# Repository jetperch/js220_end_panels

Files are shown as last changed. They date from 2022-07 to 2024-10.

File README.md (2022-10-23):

# Joulescope Front Panels

Welcome to Joulescope™ JS220 front panel hardware design project.  This project 
contains the open source hardware designs for a variety of JS220 front
panels.  These front panels customize Joulescope so that it can more easily 
connect to your power supply and target device.
For more information on Joulescope, see 
[www.joulescope.com](https://www.joulescope.com).

The [Baseline PDF](eagle/fp_baseline/fp_baseline.pdf) show the board outline
and critical dimensions.

The 2x3 connector to the main board is
[Samtec TSM-103-01-S-DV-A](https://www.samtec.com/products/tsm-103-01-s-dv-a)
([Mouser](https://www.mouser.com/ProductDetail/Samtec/TSM-103-01-S-DV-A?qs=0lQeLiL1qyYnWtGorwZW9A%3D%3D),
[Digi-Key](https://www.digikey.com/en/products/detail/TSM-103-01-S-DV-A/TSM-103-01-S-DV-A-ND/2685555))

The boards have been fabricated using PCBWay. 
Here are the order notes ([example](pcbway_order.png)):

* Size: 95 x 24.7 mm
* FR-4, TG 150-160, 1.6 thick, 6/6, 0.3 mm min hole size
* Solder Mask: Black, White silkscreen
* Surface Finish: HASL lead free, do NOT check accept ENIG substitution
* Finished Copper 1 oz

Special requests text:
The front-side surface is cosmetic.  
Reject units with scratches and blemishes.
Place all markings on back, including pcb product number.
Add flammability rating marking on back, such as 94V-0.

## License

All Joulescope front-panel designs are released under the 
permissive Apache 2.0 license.

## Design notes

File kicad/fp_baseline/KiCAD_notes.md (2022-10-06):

# KiCAD Notes

The symbol and footprint components / libraries have been generated for KiCAD V6 and are not anticipated to be backwards compatible.

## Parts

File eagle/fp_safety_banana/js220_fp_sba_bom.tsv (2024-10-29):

Quantity | Part | Designators
1 | CT3149-0 | J1
2 | CT3149-2 | J2,J3
1 | CT3149-4 | J4
1 | TSM-103-01-S-DV-A | J5
1 | JS220_fp_sba_pcb_revB | PCB1

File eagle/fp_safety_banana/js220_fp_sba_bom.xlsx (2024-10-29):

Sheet: All
BOM - All
2024 October 29
# | Qty | Ref Des | Name
1 | 1 | J1 | CT3149-0
2 | 2 | J2, J3 | CT3149-2
3 | 1 | J4 | CT3149-4
4 | 1 | J5 | TSM-103-01-S-DV-A
5 | 1 | PCB1 | JS220_fp_sba_pcb_revB
 | 6

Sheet: Top
BOM - Top
2024 October 29
# | Qty | Ref Des | Name
1 | 1 | J1 | CT3149-0
2 | 2 | J2, J3 | CT3149-2
3 | 1 | J4 | CT3149-4
4 | 1 | J5 | TSM-103-01-S-DV-A
5 | 1 | PCB1 | JS220_fp_sba_pcb_revB
 | 6

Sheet: Bottom
BOM - Bottom
2024 October 29
# | Qty | Ref Des | Name
 | 0

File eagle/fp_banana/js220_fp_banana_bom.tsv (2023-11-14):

Quantity | Part | Designators
1 | CT3151V1-0 | J1
2 | CT3151V1-2 | J2,J3
1 | CT3151V1-4 | J4
1 | TSM-103-01-S-DV-A | J5
1 | JS220_fp_banana_pcb_revA | PCB1

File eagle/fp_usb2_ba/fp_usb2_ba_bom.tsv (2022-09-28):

Quantity | Part | Designators
1 | M701-330442 | J1
1 | TSM-103-01-S-DV-A | J5
1 | UJ2-AV-1-TH | J2
1 | JS220_fp_usb2_ba_pcb_revB | PCB1

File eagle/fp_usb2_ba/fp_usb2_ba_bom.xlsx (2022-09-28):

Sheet: All
BOM - All
2022 September 28
# | Qty | Ref Des | Name
1 | 1 | J1 | M701-330442
2 | 1 | J5 | TSM-103-01-S-DV-A
3 | 1 | J2 | UJ2-AV-1-TH
4 | 1 | PCB1 | JS220_fp_usb2_ba_pcb_revB
 | 4

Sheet: Top
BOM - Top
2022 September 28
# | Qty | Ref Des | Name
1 | 1 | J1 | M701-330442
2 | 1 | J5 | TSM-103-01-S-DV-A
3 | 1 | J2 | UJ2-AV-1-TH
4 | 1 | PCB1 | JS220_fp_usb2_ba_pcb_revB
 | 4

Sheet: Bottom
BOM - Bottom
2022 September 28
# | Qty | Ref Des | Name
 | 0

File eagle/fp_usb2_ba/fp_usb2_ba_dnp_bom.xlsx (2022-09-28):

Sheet: All
BOM - All
2022 September 28
# | Qty | Ref Des | Name
1 | 3 | H1, H2, J3 | DNI
 | 3

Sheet: Top
BOM - Top
2022 September 28
# | Qty | Ref Des | Name
1 | 3 | H1, H2, J3 | DNI
 | 3

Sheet: Bottom
BOM - Bottom
2022 September 28
# | Qty | Ref Des | Name
 | 0

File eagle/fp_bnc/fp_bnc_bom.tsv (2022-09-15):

Quantity | Part | Designators
2 | 031-5329-52RFX | J1,J2
1 | TSM-103-01-S-DV-A | J5
1 | JS220_fp_bnc_pcb_revA | PCB1

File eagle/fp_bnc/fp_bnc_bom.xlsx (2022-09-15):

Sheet: All
BOM - All
2022 September 15
# | Qty | Ref Des | Name
1 | 2 | J1, J2 | 031-5329-52RFX
2 | 1 | J5 | TSM-103-01-S-DV-A
3 | 1 | PCB1 | JS220_fp_bnc_pcb_revA
 | 4

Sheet: Top
BOM - Top
2022 September 15
# | Qty | Ref Des | Name
1 | 2 | J1, J2 | 031-5329-52RFX
2 | 1 | J5 | TSM-103-01-S-DV-A
3 | 1 | PCB1 | JS220_fp_bnc_pcb_revA
 | 4

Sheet: Bottom
BOM - Bottom
2022 September 15
# | Qty | Ref Des | Name
 | 0

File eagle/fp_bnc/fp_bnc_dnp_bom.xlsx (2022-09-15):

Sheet: All
BOM - All
2022 September 15
# | Qty | Ref Des | Name
1 | 8 | C1, C2, H1, H2, J3, J4, R1, R2 | DNI
 | 8

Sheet: Top
BOM - Top
2022 September 15
# | Qty | Ref Des | Name
1 | 8 | C1, C2, H1, H2, J3, J4, R1, R2 | DNI
 | 8

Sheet: Bottom
BOM - Bottom
2022 September 15
# | Qty | Ref Des | Name
 | 0

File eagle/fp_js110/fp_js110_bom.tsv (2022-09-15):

Quantity | Part | Designators
2 | CT3149-0 | J1,J3
2 | CT3149-2 | J2,J4
1 | TSM-103-01-S-DV-A | J5
1 | JS220_fp_js110_pcb_revA | PCB1

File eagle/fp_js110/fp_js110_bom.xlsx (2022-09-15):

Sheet: All
BOM - All
2022 September 15
# | Qty | Ref Des | Name
1 | 2 | J1, J3 | CT3149-0
2 | 2 | J2, J4 | CT3149-2
3 | 1 | J5 | TSM-103-01-S-DV-A
4 | 1 | PCB1 | JS220_fp_js110_pcb_revA
 | 6

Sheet: Top
BOM - Top
2022 September 15
# | Qty | Ref Des | Name
1 | 2 | J1, J3 | CT3149-0
2 | 2 | J2, J4 | CT3149-2
3 | 1 | J5 | TSM-103-01-S-DV-A
4 | 1 | PCB1 | JS220_fp_js110_pcb_revA
 | 6

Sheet: Bottom
BOM - Bottom
2022 September 15
# | Qty | Ref Des | Name
 | 0

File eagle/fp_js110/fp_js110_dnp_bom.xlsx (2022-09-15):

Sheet: All
BOM - All
2022 September 15
# | Qty | Ref Des | Name
1 | 4 | H1, H2, J6, R1 | DNI
 | 4

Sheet: Top
BOM - Top
2022 September 15
# | Qty | Ref Des | Name
1 | 4 | H1, H2, J6, R1 | DNI
 | 4

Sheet: Bottom
BOM - Bottom
2022 September 15
# | Qty | Ref Des | Name
 | 0

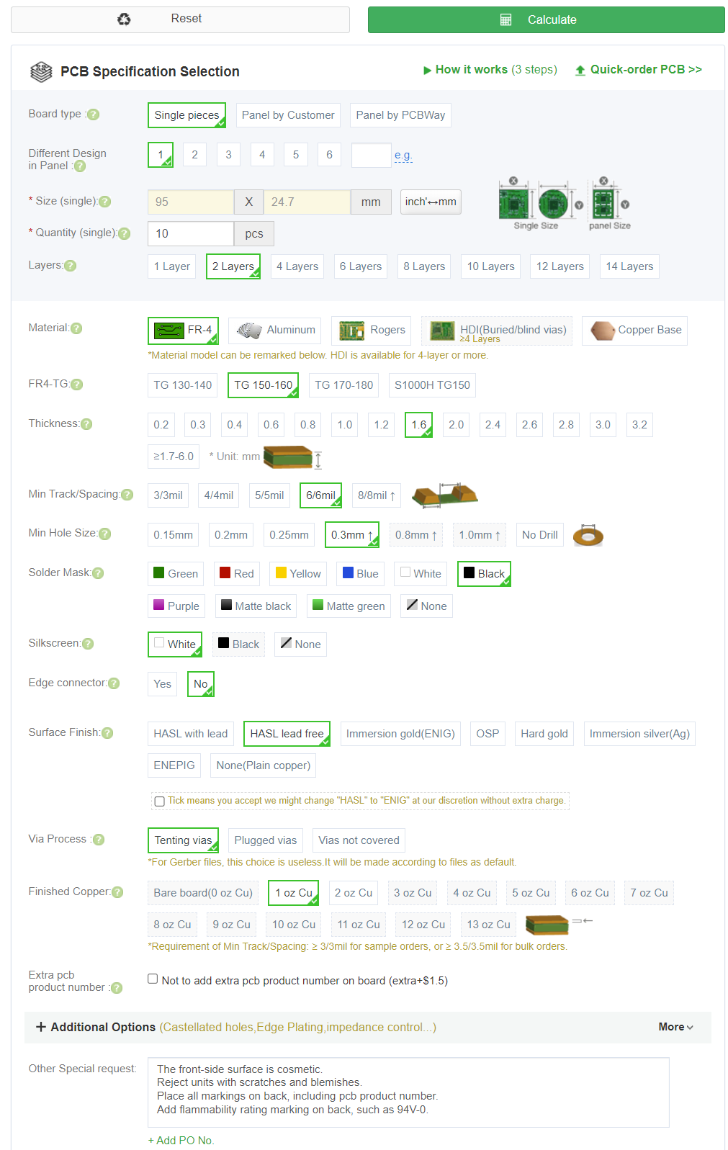
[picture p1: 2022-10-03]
pcbway_order.png

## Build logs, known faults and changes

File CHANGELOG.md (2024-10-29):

# CHANGELOG

This file contains the list of changes made to joulescope_front_panels.

## 1.1.0

2024 Oct 29

* Added JS220 Safety Banana Jack front panel.

## 1.0.3

2022 Oct 23

* Added connector part number to README.

## 1.0.2

2022 Oct 3

* Improved fp_baseline dimensioning.
* Added fp_baseline.pdf.
* First public release.
* Added PCBWay order example.

## 1.0.1

2022 Sep 28

* Fixed fb_usb2_ba connector A USB connector holes.

## 1.0.0

2022 Sep 15

* Updated back panel for production build.
  * Increased USB hole size by 0.2 mm in left, right, and up directions
  * Bumped rev from C to D.
* Added additional boards:
  * fb_usb2_ba: USB 2.0 B/A connector
  * fp_bnc: BNC & 0.1" headers
  * fp_js110: Safety banana jacks configured like the JS110.
  * fp_baseline: Starting point for creating new boards in Eagle.

## 0.3.0

2022 Jun 16

* Updated binding post front panel for beta build.
  * Decreased TSM-103-01-S-DV-A alignment holes from 0.068" to 0.065".
    Spec'ed sized is 0.063"
* Updated back panel for beta build.
  * Increased USB hole size by 0.15 mm in all directions.
  * Fixed BNC hole.
    * Decreased diameter from 10.45 to 10.05 mm.
    * Moved up from 11.555 mm to 12.355 to account for PCB thickness.
    * Tighted up polarizing holes vertically & horizontally.

## 0.2.0

2022 Feb 17

* Updated for JS220 p3.

## 0.1.0

2021 Jul 23

* Initial release with binding post front panel and back panel.

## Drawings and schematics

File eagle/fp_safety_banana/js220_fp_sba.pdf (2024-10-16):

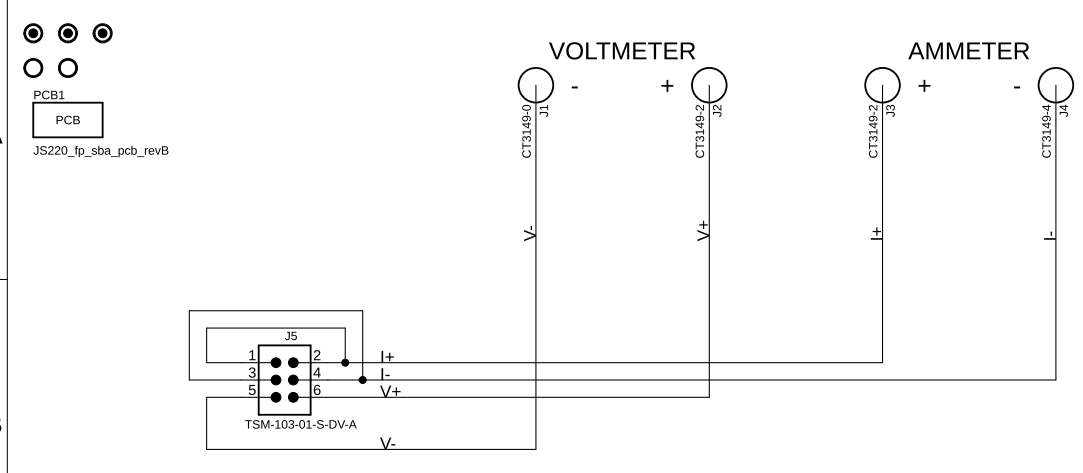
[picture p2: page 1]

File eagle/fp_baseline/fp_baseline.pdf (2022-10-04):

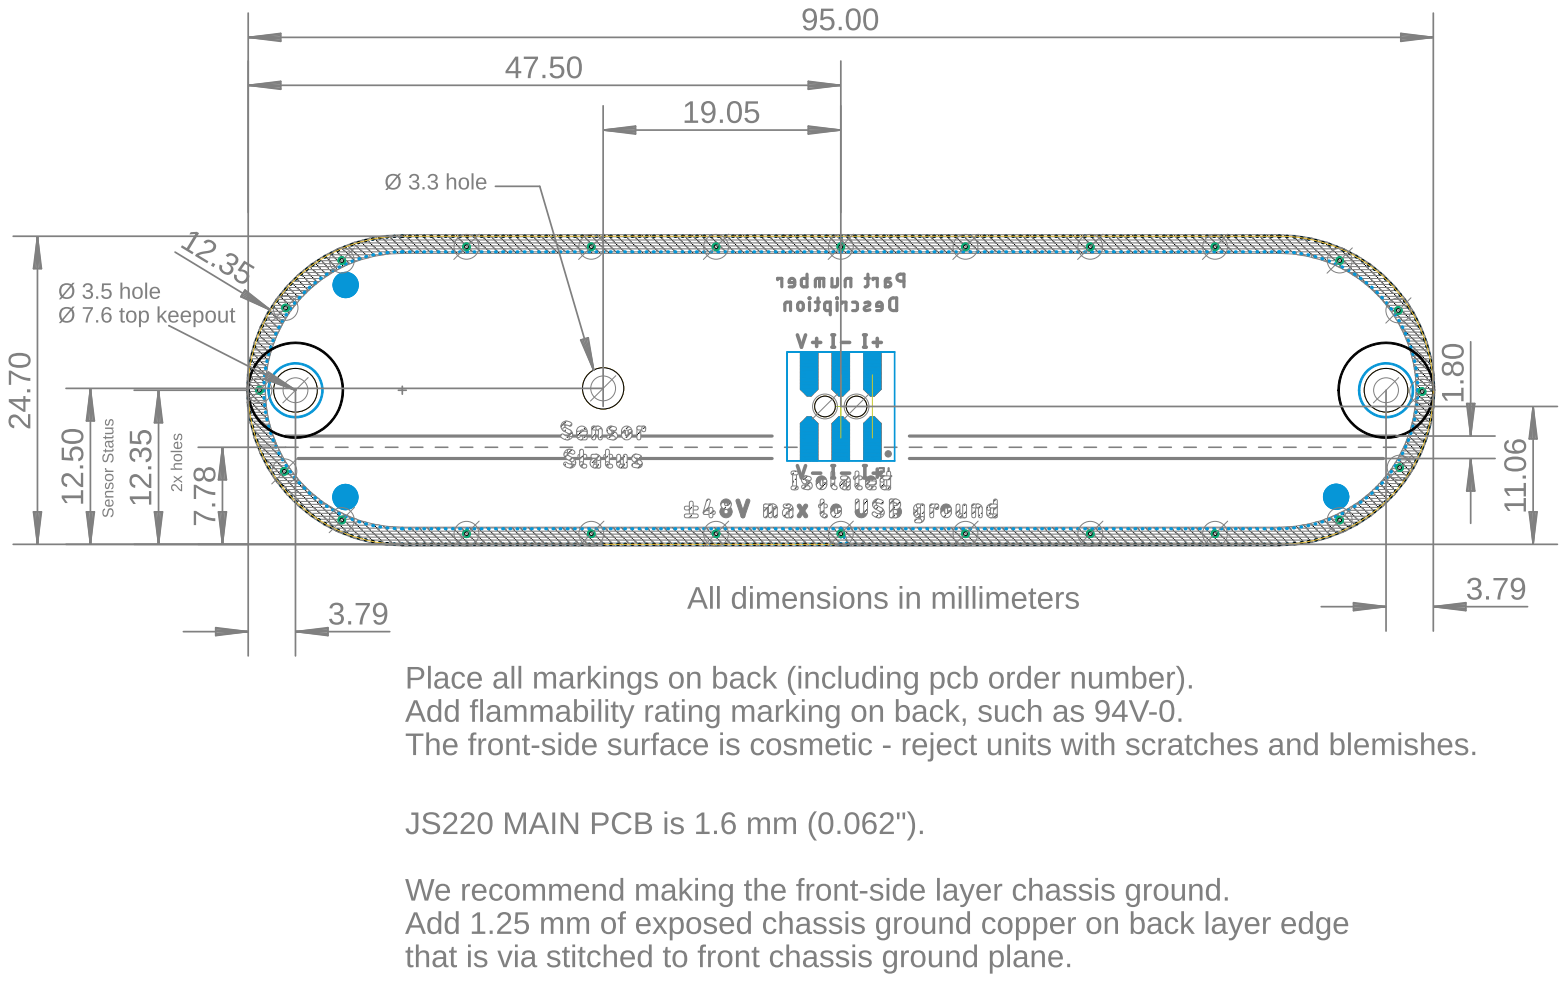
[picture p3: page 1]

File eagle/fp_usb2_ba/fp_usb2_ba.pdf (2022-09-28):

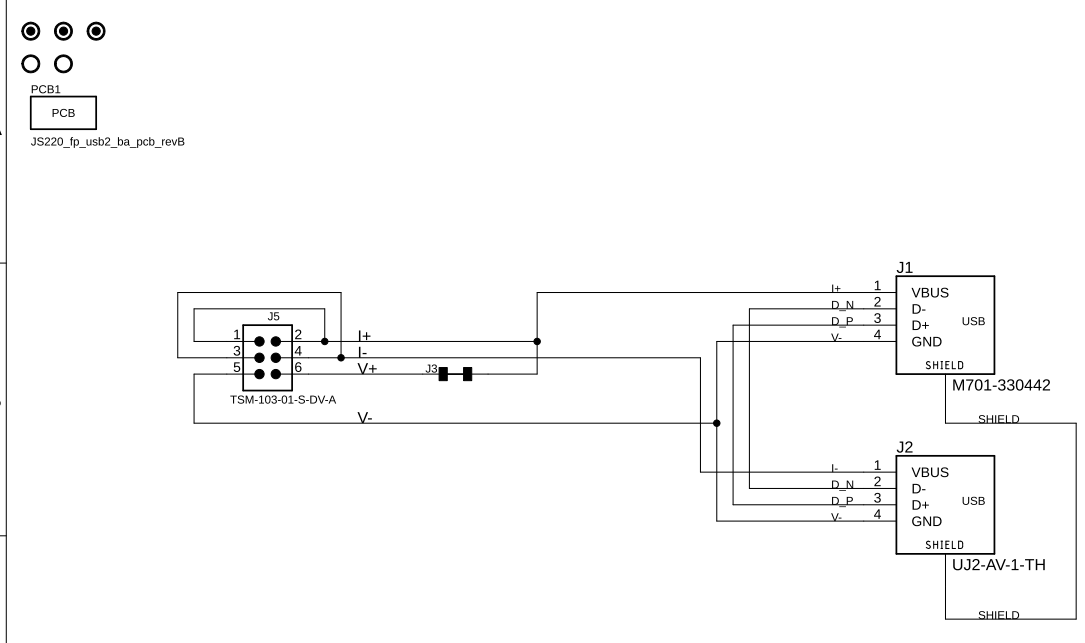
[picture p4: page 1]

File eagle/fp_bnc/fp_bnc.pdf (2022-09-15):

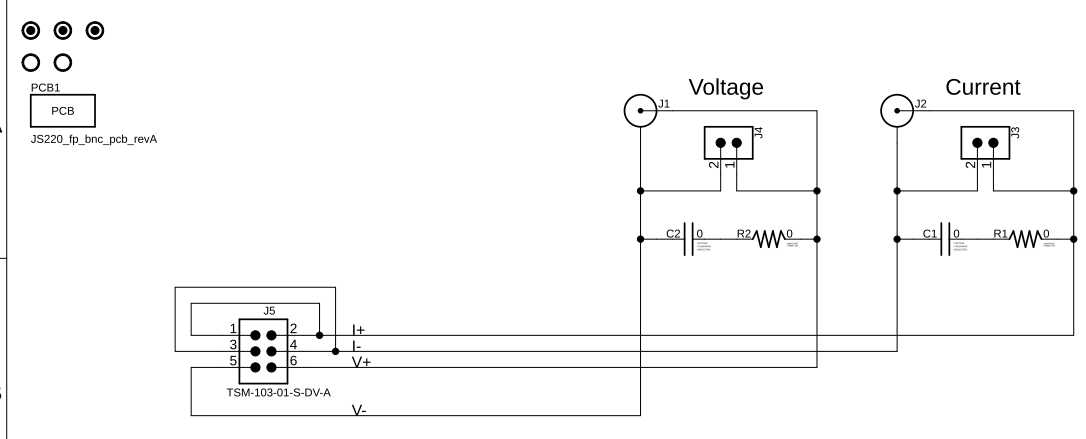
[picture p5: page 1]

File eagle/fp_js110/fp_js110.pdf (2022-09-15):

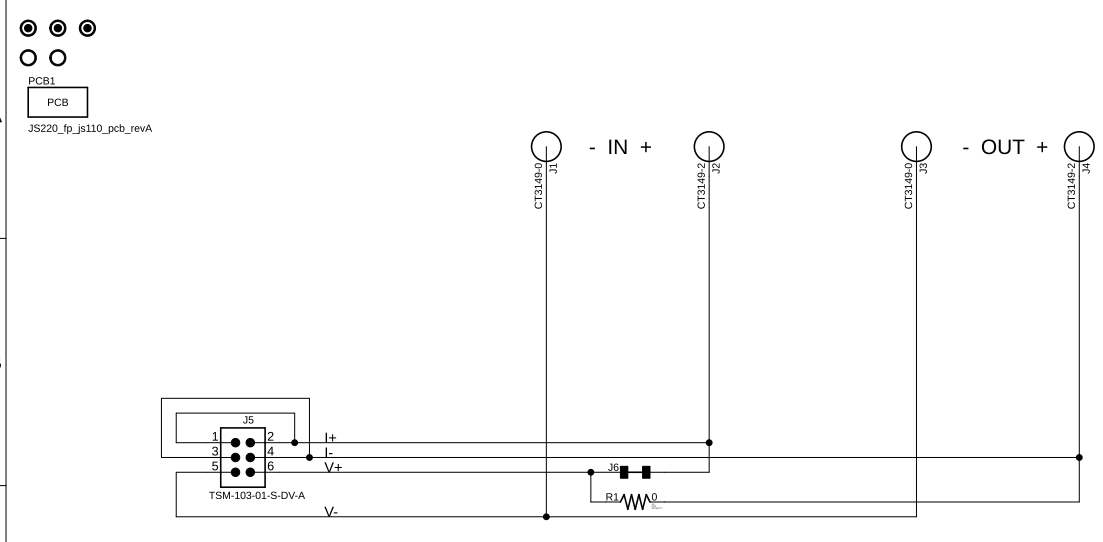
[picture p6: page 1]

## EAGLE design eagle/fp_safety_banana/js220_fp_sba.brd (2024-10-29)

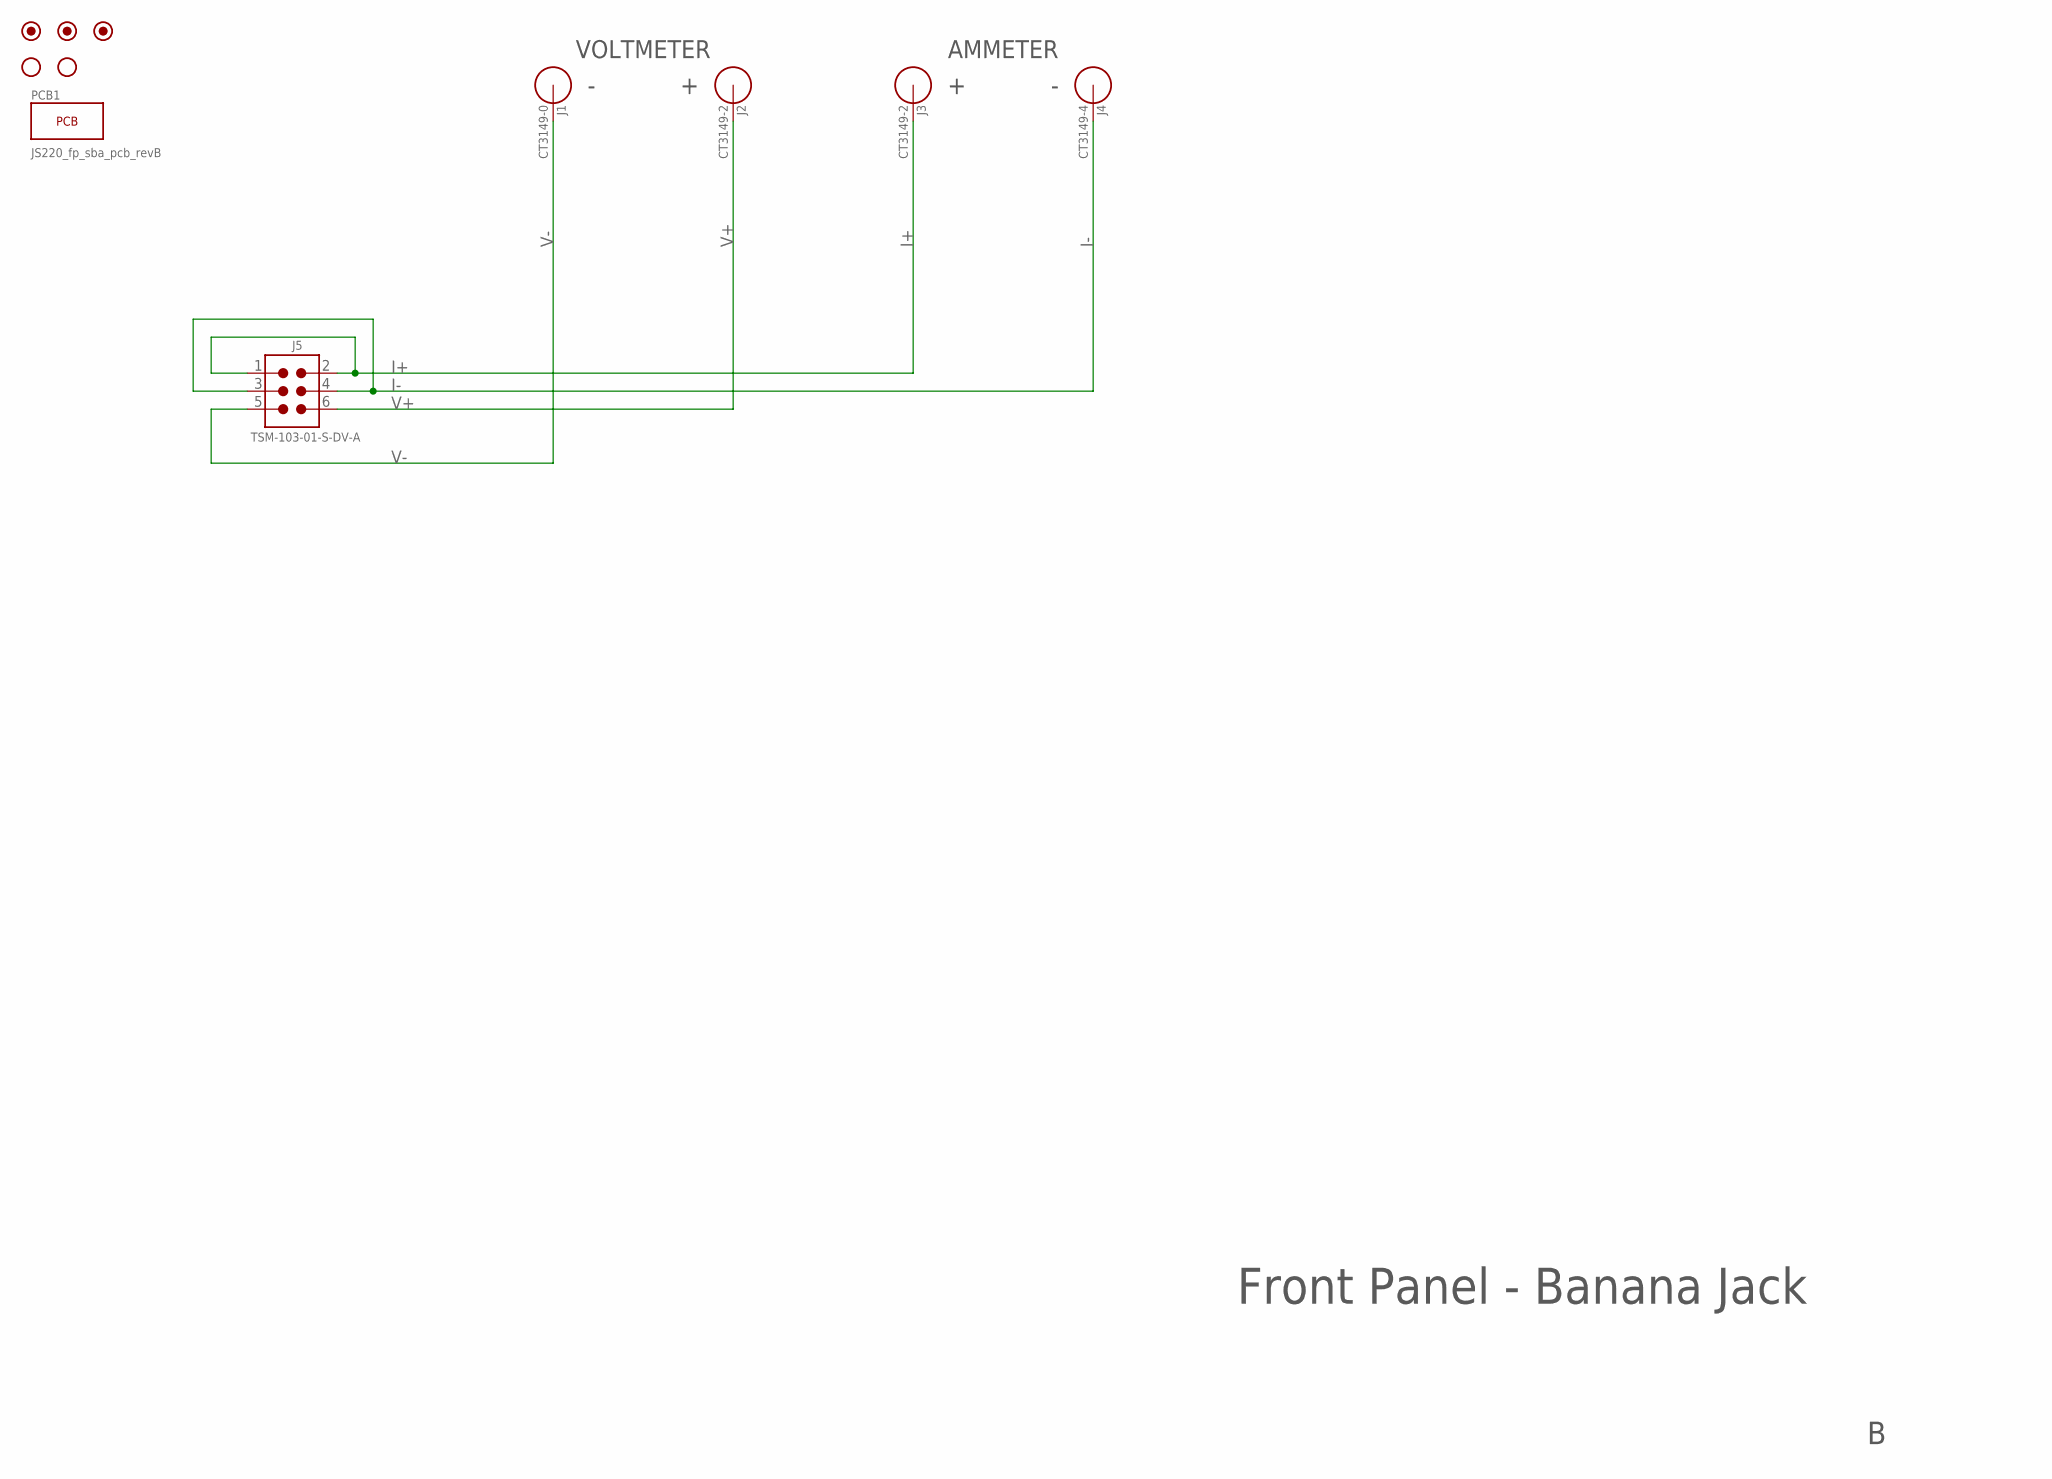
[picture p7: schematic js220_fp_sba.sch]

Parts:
FUD1, FUD2, FUD3: FIDUCIAL_1MM; FIDUCIAL_1MM_2MM
H1, H2: HOLE_#6_NORESTRICT; HOLE_3.5MM_NORESTRICT
J1: CT3149-0; CT3149
J2, J3: CT3149-2; CT3149
J4: CT3149-4; CT3149
J5: TSM-103-01-S-DV-A; CONN_0.1_3X2_MSA; MPN TSM-103-01-S-DV-A

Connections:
I+: J3.A, J5.1, J5.2
I-: J4.A, J5.3, J5.4
V+: J2.A, J5.6
V-: J1.A, J5.5

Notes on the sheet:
Front Panel - Banana Jack
+ -
AMMETER
VOLTMETER
- +

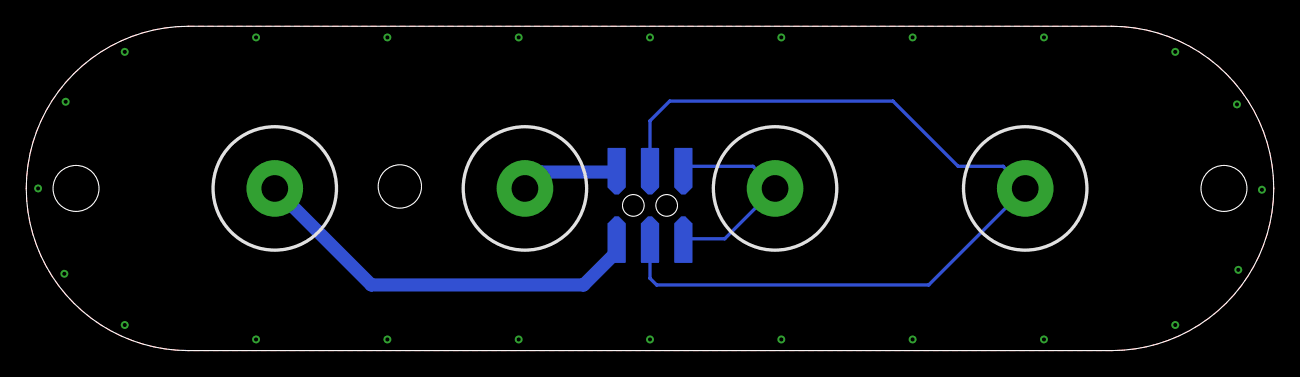
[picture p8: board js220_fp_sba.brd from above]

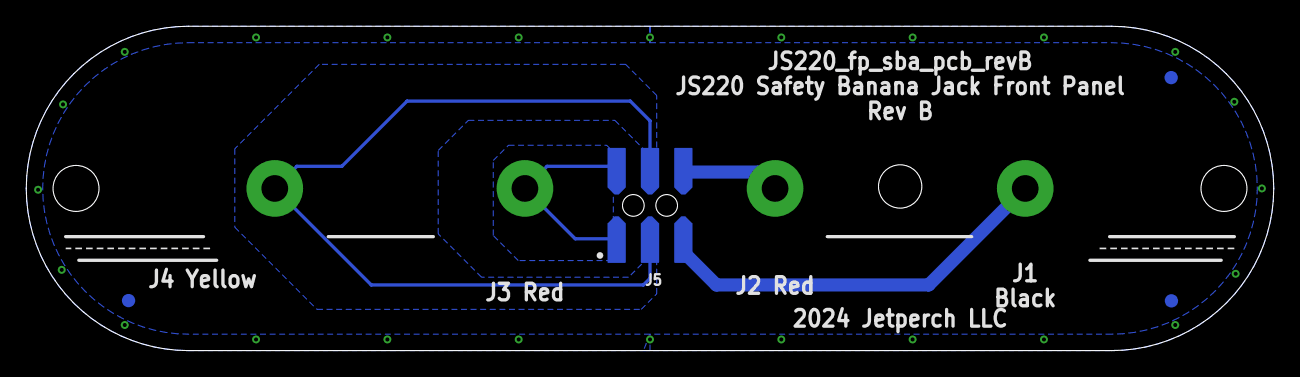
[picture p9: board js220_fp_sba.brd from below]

Board: 2 copper layers, 95.0 x 24.7 mm, 10 parts (4 on the bottom side), 4 nets.

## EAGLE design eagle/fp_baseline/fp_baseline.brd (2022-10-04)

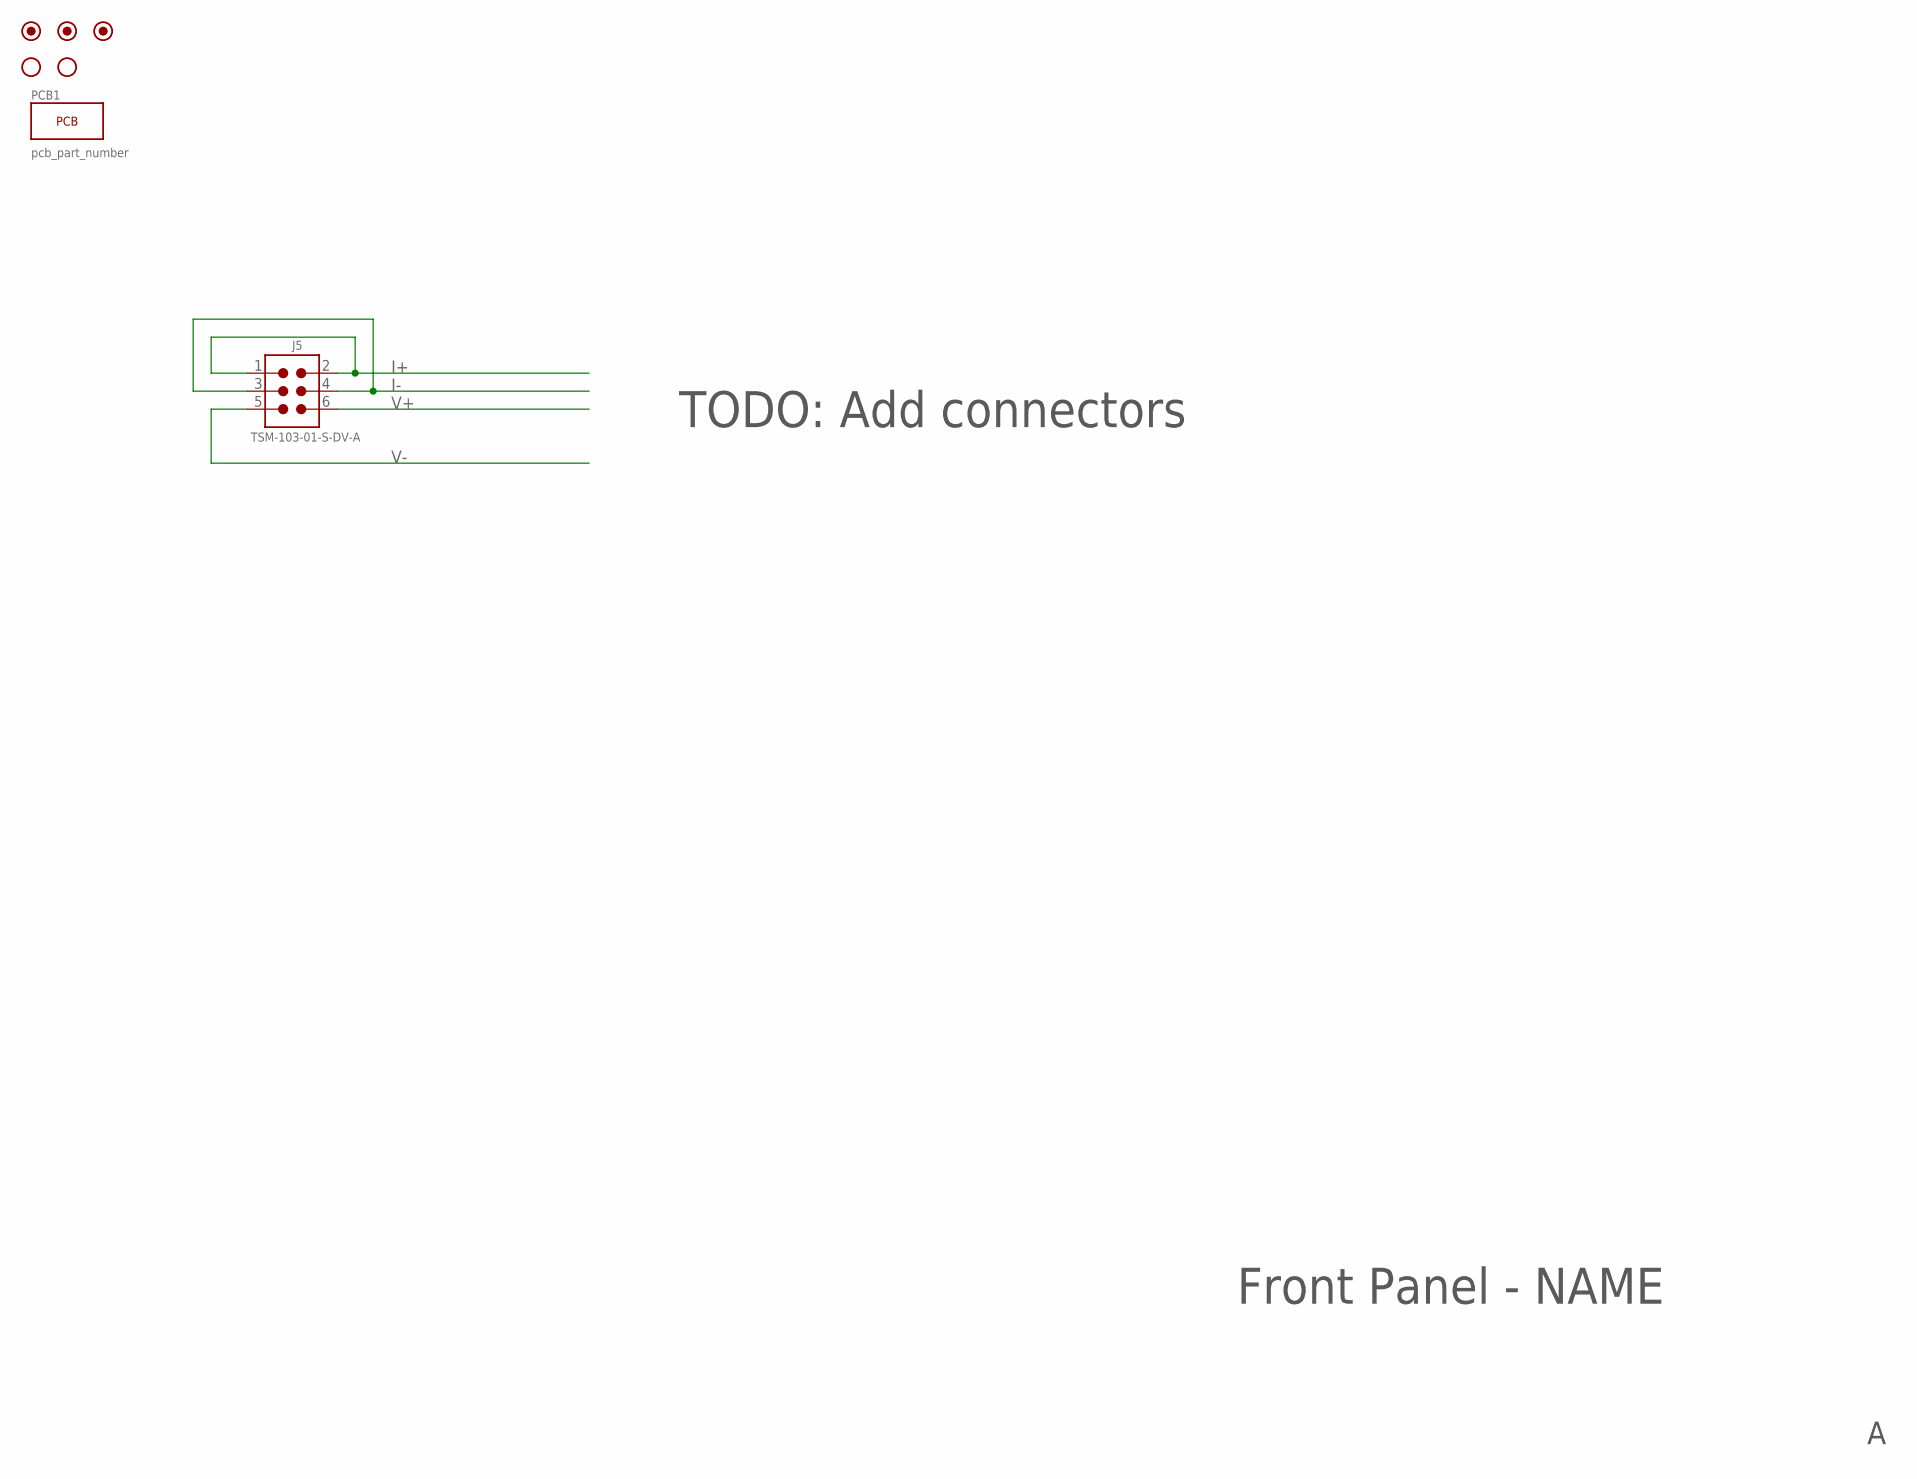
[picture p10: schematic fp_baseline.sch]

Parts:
FUD1, FUD2, FUD3: FIDUCIAL_1MM; FIDUCIAL_1MM_2MM
H1, H2: HOLE_#6_NORESTRICT; HOLE_3.5MM_NORESTRICT
J5: TSM-103-01-S-DV-A; CONN_0.1_3X2_MSA; MPN TSM-103-01-S-DV-A

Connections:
I+: J5.1, J5.2
I-: J5.3, J5.4
V+: J5.6
V-: J5.5

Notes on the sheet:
Front Panel - NAME
TODO: Add connectors

Board: 2 copper layers, 6 parts (4 on the bottom side), 2 nets, no tracks yet.

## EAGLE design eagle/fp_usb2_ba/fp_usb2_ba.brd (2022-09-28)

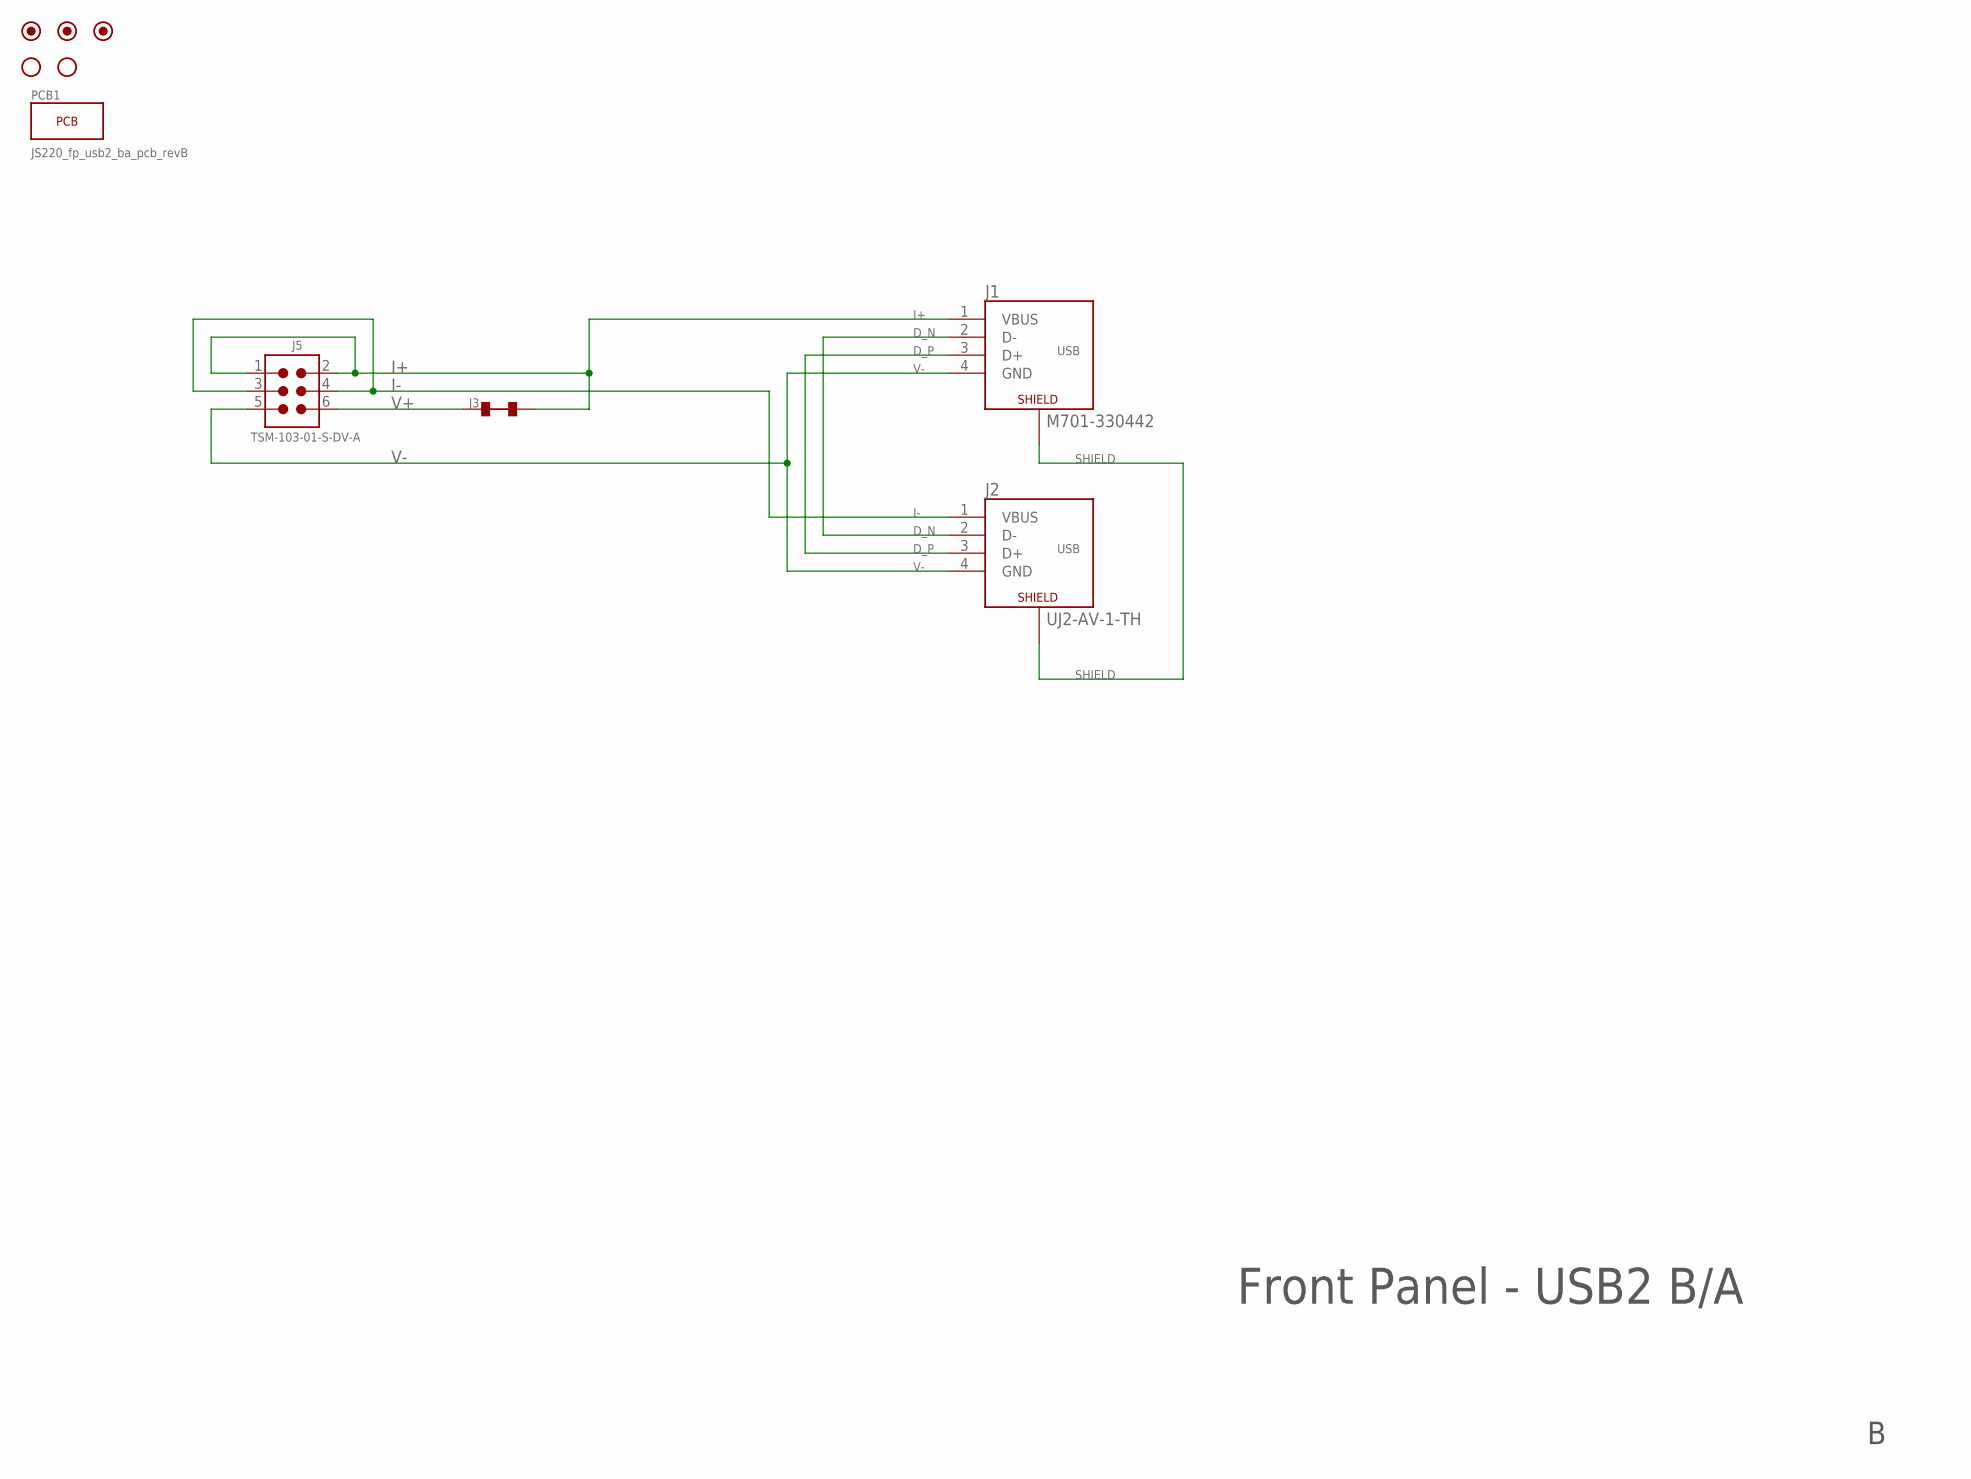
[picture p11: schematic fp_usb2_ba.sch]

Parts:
FUD1, FUD2, FUD3: FIDUCIAL_1MM; FIDUCIAL_1MM_2MM
H1, H2: HOLE_#6_NORESTRICT; HOLE_3.5MM_NORESTRICT
J1: M701-330442; USB-B-VTH
J2: UJ2-AV-1-TH; USB-A-VTH
J3: TRACE_CUT0603; J0603
J5: TSM-103-01-S-DV-A; CONN_0.1_3X2_MSA; MPN TSM-103-01-S-DV-A

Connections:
D_N: J1.2 (D-), J2.2 (D-)
D_P: J1.3 (D+), J2.3 (D+)
I+: J1.1 (VBUS), J3.2, J5.1, J5.2
I-: J2.1 (VBUS), J5.3, J5.4
SHIELD: J1.SHIELD@1 (SHIELD), J1.SHIELD@3 (SHIELD), J2.SHIELD@1 (SHIELD), J2.SHIELD@3 (SHIELD)
V+: J3.1, J5.6
V-: J1.4 (GND), J2.4 (GND), J5.5

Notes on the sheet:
Front Panel - USB2 B/A

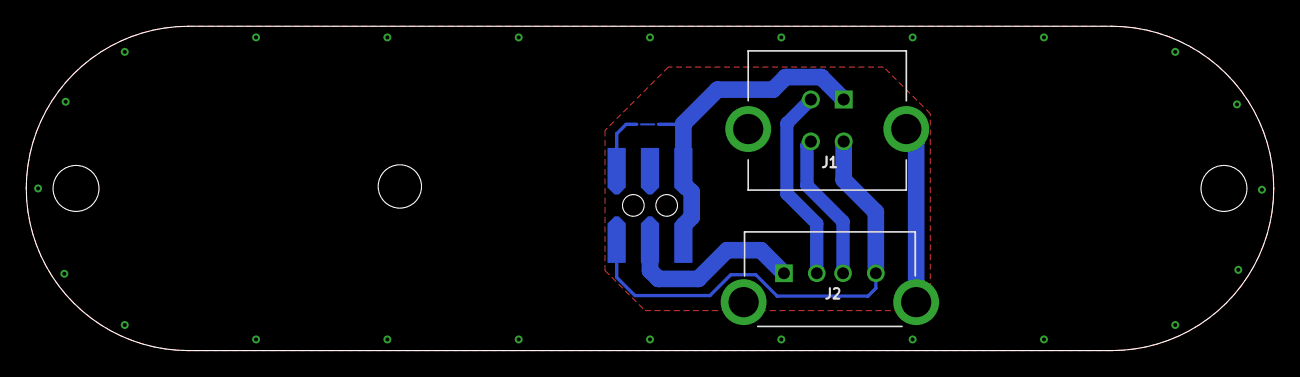
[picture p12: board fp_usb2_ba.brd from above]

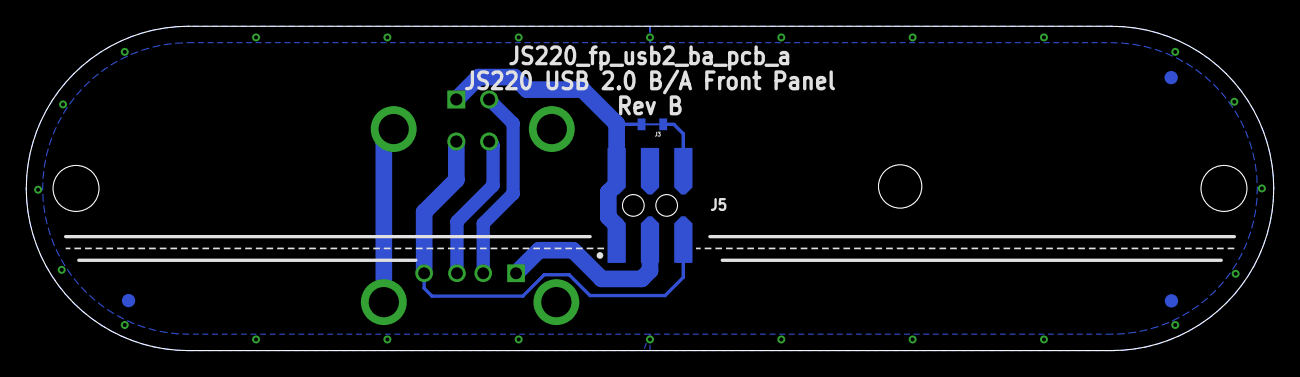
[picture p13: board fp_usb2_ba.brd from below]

Board: 2 copper layers, 95.0 x 24.7 mm, 9 parts (5 on the bottom side), 7 nets.

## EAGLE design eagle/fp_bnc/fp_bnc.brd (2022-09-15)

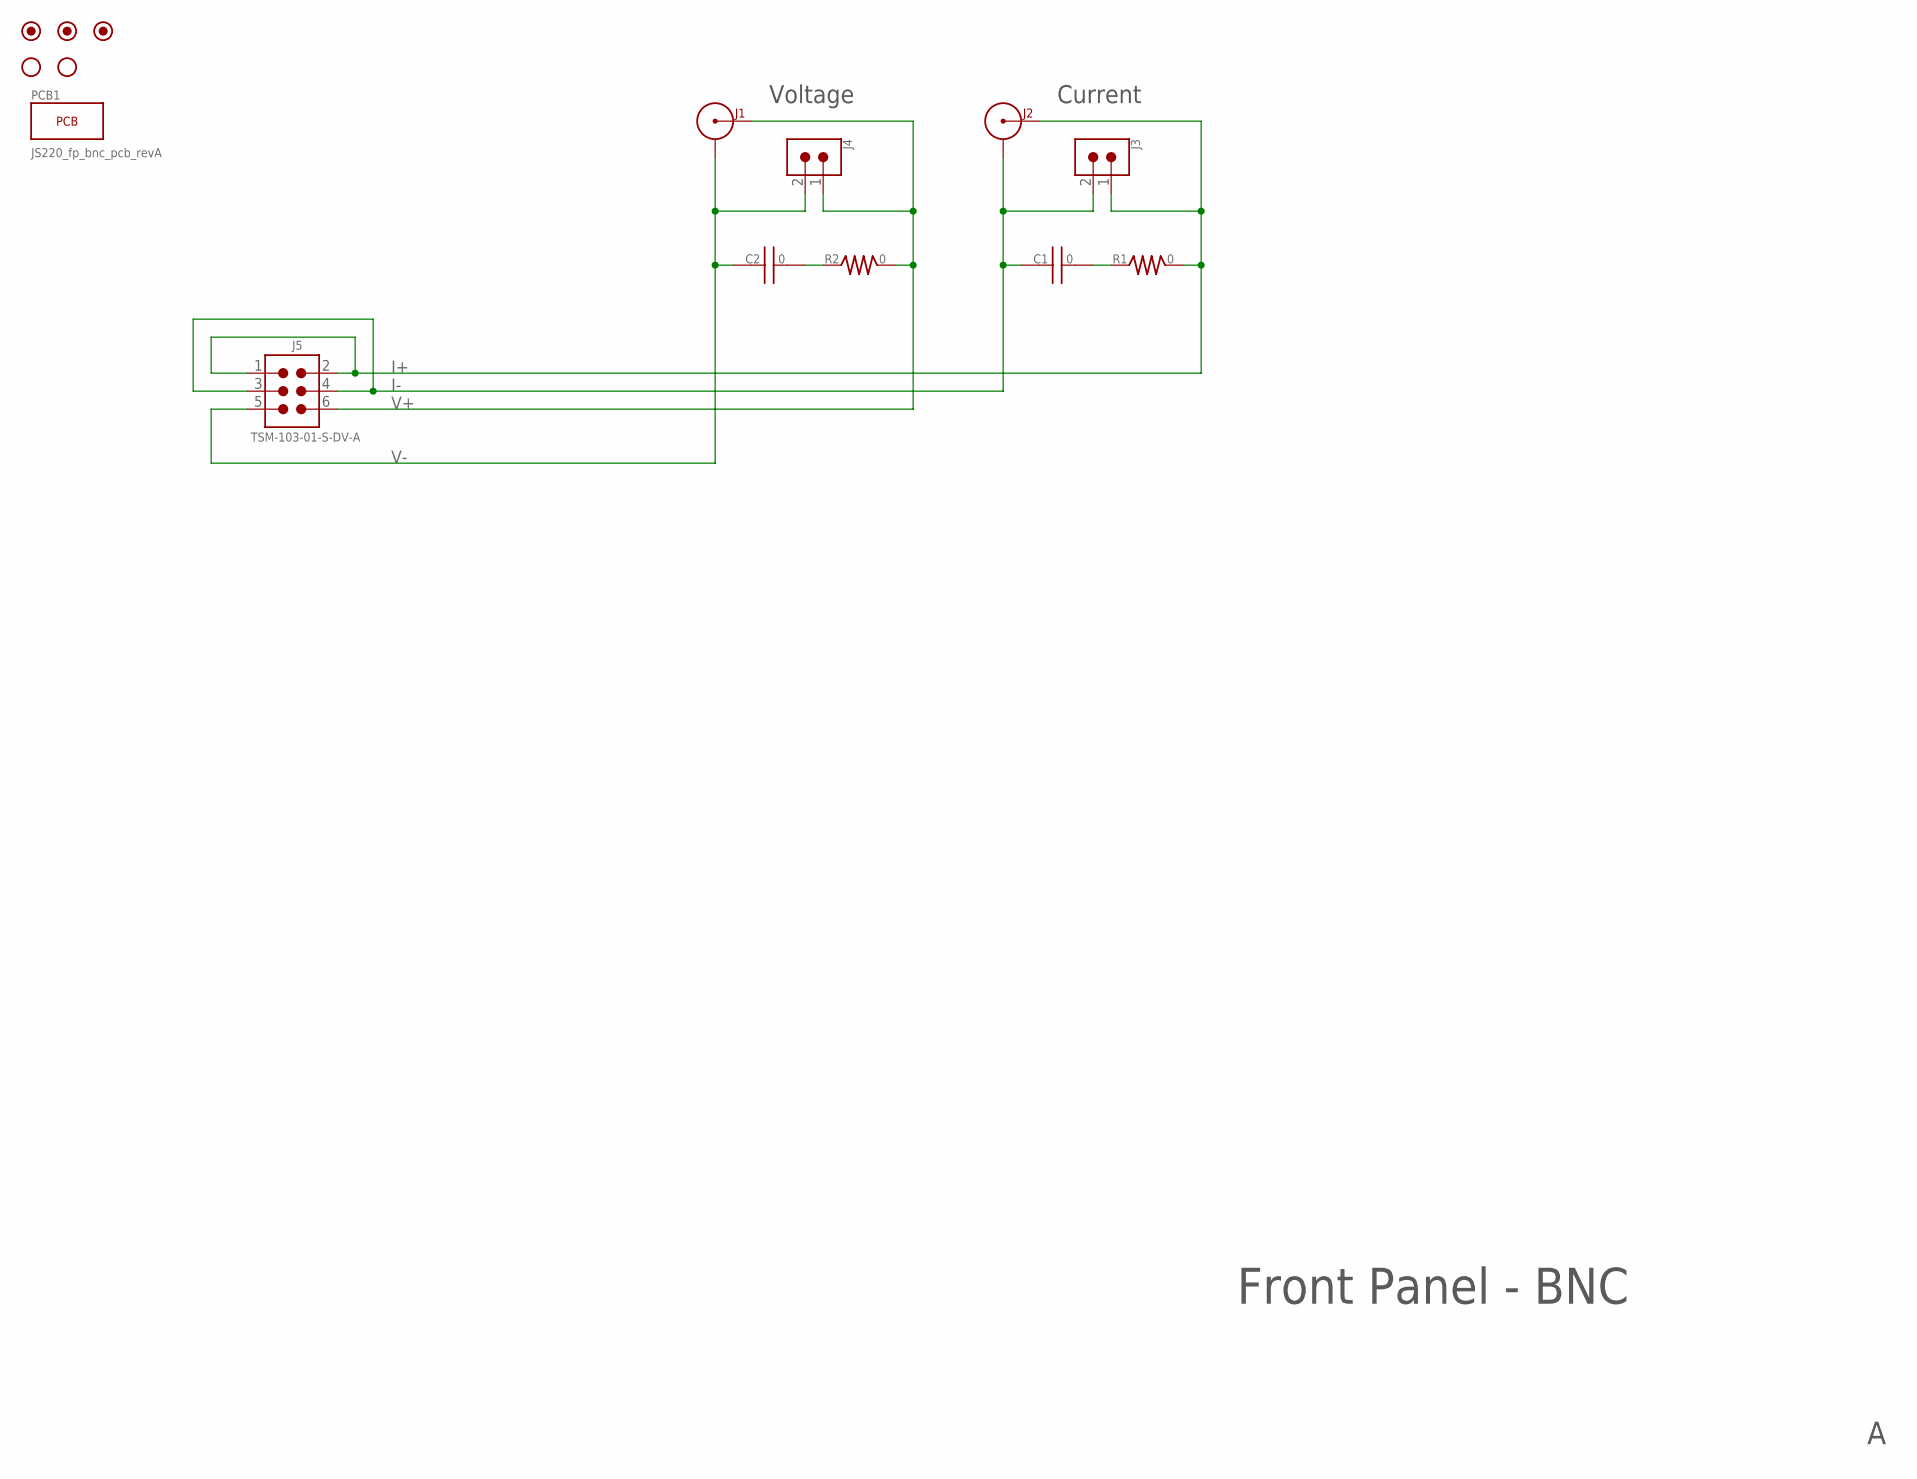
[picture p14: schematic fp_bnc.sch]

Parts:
C1, C2: 0; 0603
FUD1, FUD2, FUD3: FIDUCIAL_1MM; FIDUCIAL_1MM_2MM
H1, H2: HOLE_#6_NORESTRICT; HOLE_3.5MM_NORESTRICT
J1, J2: 031-5329-52RFX; BNC_31-5329-52RFX; MPN 031-5329-52RFX
J3, J4: CONN_0.1_2X1; CONN_0.1_2X1_M
J5: TSM-103-01-S-DV-A; CONN_0.1_3X2_MSA; MPN TSM-103-01-S-DV-A
R1, R2: 0; 1206; TOLERANCE 1%

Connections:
I+: J2.SIGNAL, J3.1, J5.1, J5.2, R1.2
I-: C1.1, J2.G@1 (SHIELD), J2.G@2 (SHIELD), J2.G@3 (SHIELD), J2.G@4 (SHIELD), J3.2, J5.3, J5.4
I_T: C1.2, R1.1
V+: J1.SIGNAL, J4.1, J5.6, R2.2
V-: C2.1, J1.G@1 (SHIELD), J1.G@2 (SHIELD), J1.G@3 (SHIELD), J1.G@4 (SHIELD), J4.2, J5.5
V_T: C2.2, R2.1

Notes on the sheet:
Front Panel - BNC
Voltage
Current

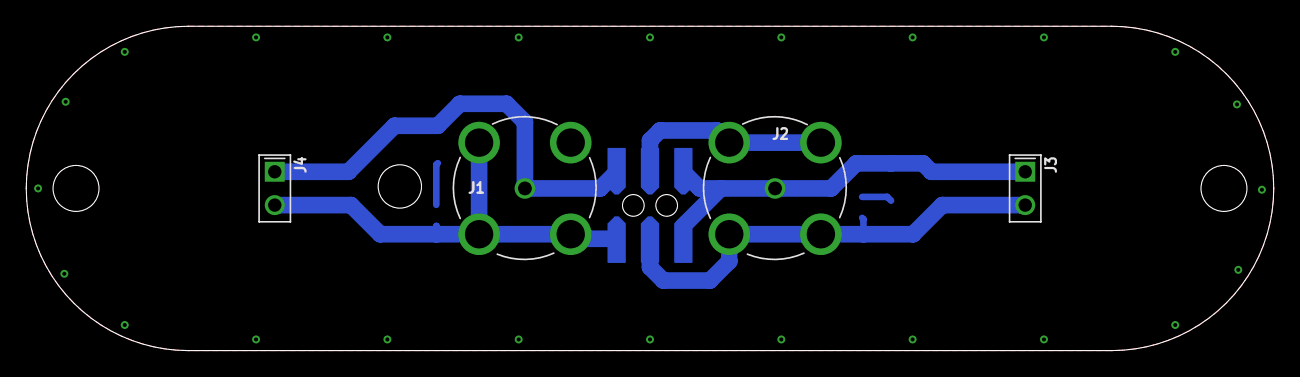
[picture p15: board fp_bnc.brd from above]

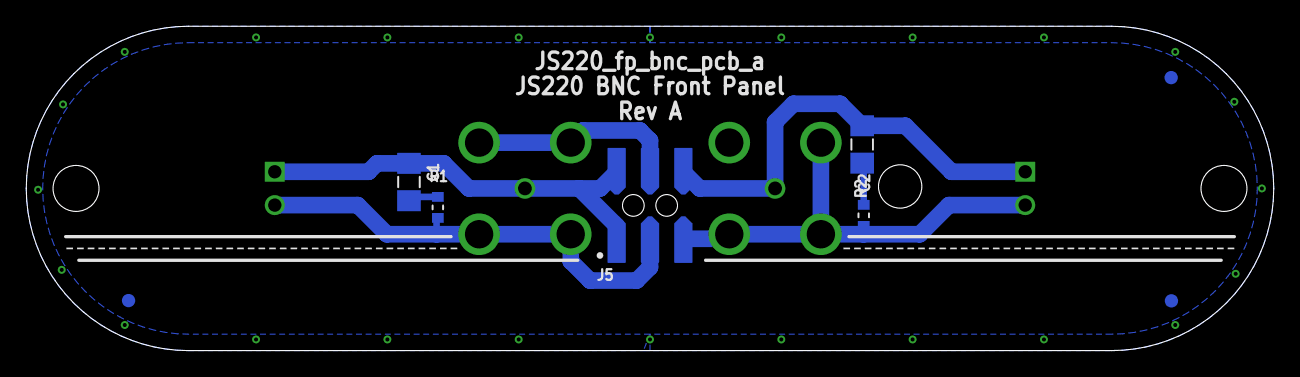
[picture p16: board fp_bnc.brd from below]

Board: 2 copper layers, 95.0 x 24.7 mm, 14 parts (8 on the bottom side), 6 nets.

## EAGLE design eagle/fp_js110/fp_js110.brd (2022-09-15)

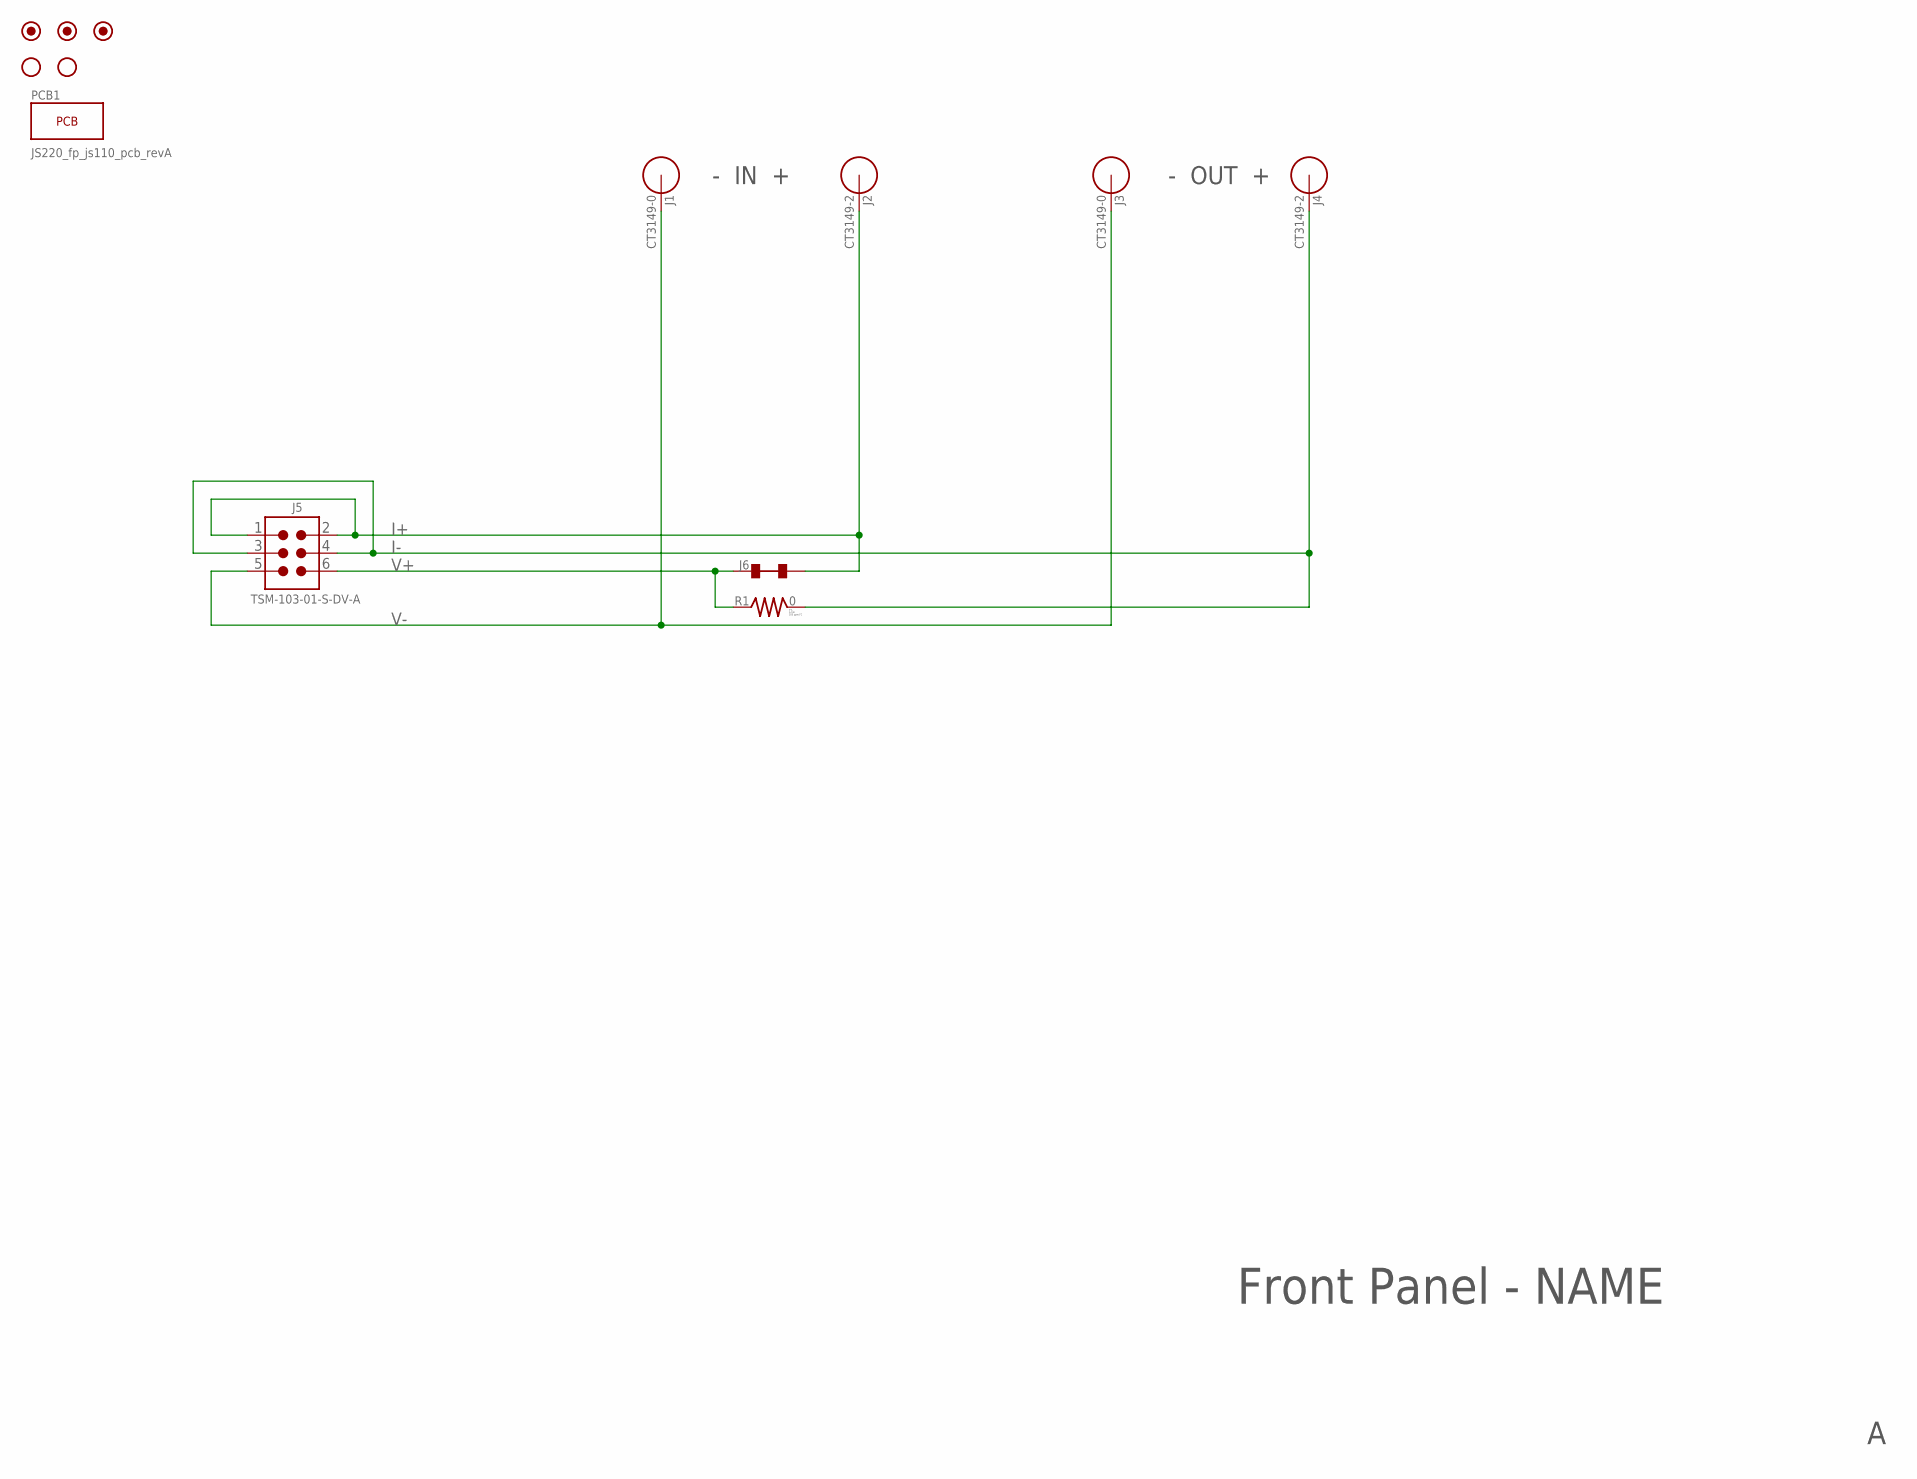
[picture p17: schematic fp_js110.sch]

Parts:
FUD1, FUD2, FUD3: FIDUCIAL_1MM; FIDUCIAL_1MM_2MM
H1, H2: HOLE_#6_NORESTRICT; HOLE_3.5MM_NORESTRICT
J1, J3: CT3149-0; CT3149
J2, J4: CT3149-2; CT3149
J5: TSM-103-01-S-DV-A; CONN_0.1_3X2_MSA; MPN TSM-103-01-S-DV-A
J6: TRACE_CUT0603; J0603
R1: 0; 0603

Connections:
I+: J2.A, J5.1, J5.2, J6.2
I-: J4.A, J5.3, J5.4, R1.2
V+: J5.6, J6.1, R1.1
V-: J1.A, J3.A, J5.5

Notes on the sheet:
Front Panel - NAME
- IN +
- OUT +

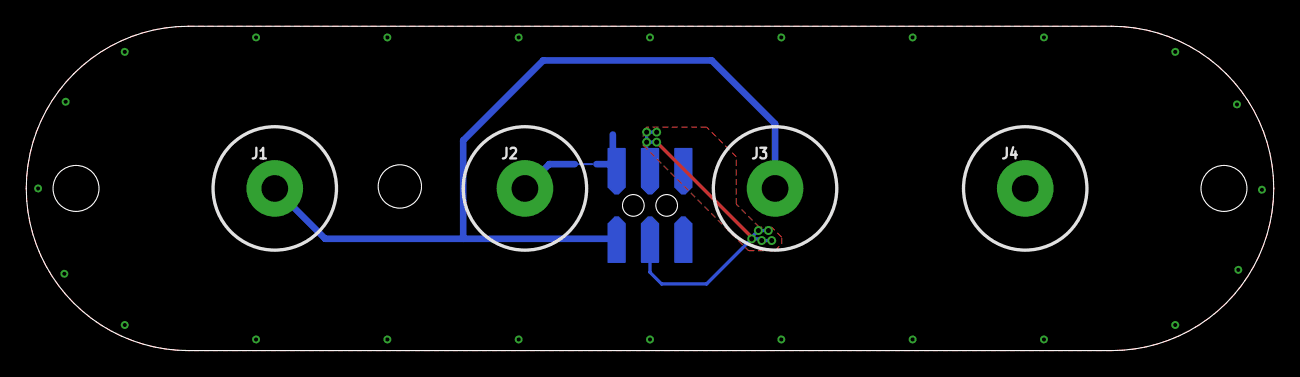
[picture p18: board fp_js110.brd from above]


Board: 2 copper layers, 95.0 x 24.7 mm, 12 parts (6 on the bottom side), 4 nets.

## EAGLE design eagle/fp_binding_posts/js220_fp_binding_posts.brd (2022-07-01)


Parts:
FUD1, FUD2, FUD3: FIDUCIAL_1MM; FIDUCIAL_1MM_2MM
H1, H2: HOLE_#6_NORESTRICT; HOLE_3.5MM_NORESTRICT
J1: 111-0703-001; BINDING_POST_6; MPN 111-0703-001
J2, J3: 111-0702-001; BINDING_POST_6; MPN 111-0702-001
J4: 111-0707-001; BINDING_POST_6; MPN 111-0707-001
J5: TSM-103-01-S-DV-A; CONN_0.1_3X2_MSA; MPN TSM-103-01-S-DV-A

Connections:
I+: J3.1, J5.1, J5.2
I-: J4.1, J5.3, J5.4
V+: J2.1, J5.6
V-: J1.1, J5.5

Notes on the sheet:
Front Panel - Binding Posts
+ -
AMMETER
VOLTMETER
- +



Board: 2 copper layers, 95.0 x 24.7 mm, 10 parts (4 on the bottom side), 4 nets.

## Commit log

2021-07-23 Completed revA for the initial end panels.
    * Binding post front panel.
    * Back panel.
    [js220_bp.brd, js220_bp.sch, js220_fp_binding_posts.sch]
2022-02-12 Updated for p3
    [js220_fp_binding_posts.brd, js220_fp_binding_posts.sch]
2022-02-12 Updated to rev B.
    [js220_bp.brd, js220_fp_binding_posts.brd, js220_fp_binding_posts.sch]
2022-02-17 Updated back panel.
    [js220_bp.brd]
2022-02-17 Updated for JS220 p3.
    [js220_bp.brd, js220_bp.sch, js220_bp_bom.tsv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]
2022-02-25 Final build files.
    Fixed fp_binding_posts with corrected connector.
    [js220_fp_binding_posts.brd, js220_fp_binding_posts.sch, js220_fp_binding_posts_bom.tsv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]
2022-07-01 Updated for beta build.
    [js220_bp.brd, js220_bp.sch, js220_bp_bom.tsv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]
2022-09-15 Updates for JS220 first production build.
    * Updated back panel for production build.
    * Increased USB hole size by 0.2 mm in left, right, and up directions
    * Bumped rev from C to D.
    * Added additional boards:
    * fb_usb2_ba: USB 2.0 B/A connector
    * fp_bnc: BNC & 0.1" headers
    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
    [fp_baseline.brd, fp_baseline.sch, fp_bnc.brd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]
2022-09-28 Fixed fb_usb2_ba connector A USB connector holes.
    [fp_usb2_ba.brd, fp_usb2_ba.sch, fp_usb2_ba_bom.tsv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]
2022-10-03 Improved fp_baseline.
    * Added dimensions for all features.
    * Added chassis ground comment.
    * Added PDF.
    * First public release.
    [fp_baseline.brd]
2022-10-03 Added PCBWay order example.
2022-10-04 Updated front panel baseline with additional dimensions and detail.
    [fp_baseline.brd]
2022-10-06 Add initial KiCAD 6.0 fp_baseline, including .gitignore and notes
    [fp_baseline.kicad_pcb, fp_baseline.kicad_sch]
2022-10-23 Added connector part number to README.
2022-10-26 fix front copper polygon so it acts as prper copper pour around pads
    [fp_baseline.kicad_pcb, fp_baseline.kicad_sch]
2022-11-14 Fix wrong pin numbering on JS220 panel symbol and update schematic to match
    [fp_baseline.kicad_sch]
2023-11-14 Added safety banana jack front panel.
    [js220_fp_banana.brd, js220_fp_banana.sch, js220_fp_banana_bom.tsv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]
2024-01-12 Renamed js220_fp_banana to js220_fp_sba
    [js220_fp_banana_bom.xlsx, js220_fp_sba.brd, js220_fp_sba.sch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]
2024-10-16 Added safety banana jack rev B with same connectors as JS110
    [js220_fp_sba.brd, js220_fp_sba.sch, js220_fp_sba_bom.tsv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]
2024-10-29 Added JS220 Safety Banana Jack front panel.
    Fixed connector part numbers for BOM.
    [js220_fp_sba.brd, js220_fp_sba.sch, js220_fp_sba_bom.tsv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]
